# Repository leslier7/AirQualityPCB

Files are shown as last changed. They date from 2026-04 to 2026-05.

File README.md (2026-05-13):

# Air Quality PCB

A custom air quality monitoring device with an ESP32-C3 microcontroller, designed to measure environmental sensor data and transmit it over WiFi and LoRa.

## Repository Structure

```
AirQualityPCB/
├── PCB/        # KiCad schematic, layout, BOM, and fabrication outputs
└── Firmware/   # PlatformIO firmware for the ESP32-C3
```

## PCB

The PCB was designed in KiCad and lives in the [PCB/](PCB/) folder. This folder contains the schematic, board layout, and a custom component library (3D models, footprints, and symbols).

The BOM, STEP file, and Gerbers can be found on the [GitHub Releases](https://github.com/leslier7/AirQualityPCB/releases) page. They can also be extracted from the KiCAD project.

## Firmware

The firmware is written in C++ using the PlatformIO build system and targets the ESP32-C3.

For instructions on setting up the development environment, building, and flashing the firmware, see [Firmware/README.md](Firmware/README.md).

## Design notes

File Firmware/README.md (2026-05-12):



# About
Firmware for the Air Quality Monitoring board. Runs on an ESP32-C3 and reads the following sensors every 1.5–3 seconds, averaging the results before transmission:

| Sensor | Measurements |
|---|---|
| Bosch BME688 | Temperature, Humidity, Pressure, VOC gas resistance |
| CH4 sensor (UART) | Methane (ppm) |
| H2S sensor (I2C via ADS1X15 ADC) | Hydrogen sulfide (ppm) |
| NO2 sensor (I2C via ADS1X15 ADC) | Nitrogen dioxide (ppm) |

Data is transmitted over LoRaWAN to [The Things Network](https://www.thethingsnetwork.org/) every 15 minutes. Uplinks are unconfirmed by default; a confirmed uplink (which solicits an ACK downlink from TTN) is sent at most every 10th transmission to stay within TTN's fair use policy of 10 downlink messages per 24 hours.

### Packet Format
All fields are little-endian integers transmitted over LoRaWAN port 1.

| Field | Type | Scale | Range | Unit |
|---|---|---|---|---|
| `ch4` | `uint16` | ×1 | 0–65535 | ppm |
| `h2s` | `uint16` | ×100 | 0–5000 → 0.00–50.00 | ppm |
| `nox` | `uint16` | ×100 | 0–30000 → 0.00–300.00 | ppm |
| `voc_load` | `uint16` | ×1 | 0–65535 | (1/Ω)×10⁶×10 |
| `temp` | `int16` | ×100 | -4000–8500 → -40.00–85.00 | °C |
| `humidity` | `uint16` | ×100 | 0–10000 → 0.00–100.00 | %RH |
| `pressure` | `uint16` | ×10 | — | hPa |

---

# Contributing Guidelines

### Development Environment Setup
1. Install a C/C++ IDE which supports PlatformIO (e.g. [Visual Studio Code](https://code.visualstudio.com/), [CLion](https://www.jetbrains.com/clion/)).
2. Install [PlatformIO](https://platformio.org/install/) as an extension in your IDE.
3. Open the `Firmware` folder in your IDE.
4. Open the PlatformIO Home from the PlatformIO extension in your IDE.
5. Make sure to select the environment which corresponds to the board you are using (see **Build Environments** below).
6. Build the project using the PlatformIO build button.
7. Upload the project to the ESP32-C3 board using the PlatformIO upload button.
8. Open the serial monitor to view the output. (If using CLion, use the CLion Serial Monitor Plugin rather than the built-in upload-and-monitor button.)
9. Make changes to the code and test them on the board.
10. If you are adding new libraries, add them to `platformio.ini`.
11. Develop your changes in a separate Git branch.

### Build Environments

| Environment | Description |
|---|---|
| `lora` | Standard LoRaWAN build — use this for production |
| `test` | LoRaWAN build with zeroed sensor values (safe for RF testing without real sensors) |
| `long-range` | LoRaWAN build using SF10 for extended range |
| `long-range-debug` | SF10 build with confirmed uplinks on every TX (exceeds TTN fair use — bench only) |
| `wifi` | WiFi build (development/alternative transport) |

Select the environment from the PlatformIO toolbar before building and uploading.

### Code Style
TODO

### Pull Request Guidelines
Please write a brief description of what your code changed and why. Set yourself as the assignee and assign Robbie (leslier7) as the reviewer. Do not merge until Robbie has reviewed and approved.

# Configuration

### LoRa Configuration
To connect the board to The Things Network via LoRaWAN, you need a `keys.h` file containing your device credentials. **This file must never be committed to version control.**

1. Register your device in the [TTN Console](https://console.cloud.thethings.network/) using OTAA activation.
2. Create a new file named `keys.h` in the `include` directory.
3. Copy and paste the following template into `keys.h`:

```c
#include "stdint.h"
#ifndef KEYS_H
#define KEYS_H

// App EUI — 8 bytes, LSB first (from TTN console, "JoinEUI")
const uint8_t PROGMEM APPEUI[8] = { 0x00, 0x00, 0x00, 0x00, 0x00, 0x00, 0x00, 0x00 };

// Dev EUI — 8 bytes, LSB first (from TTN console, copy as "lsb" byte order)
const uint8_t PROGMEM DEVEUI[8] = { 0x00, 0x00, 0x00, 0x00, 0x00, 0x00, 0x00, 0x00 };

// App Key — 16 bytes, MSB first (from TTN console, copy as "msb" byte order)
const uint8_t PROGMEM APPKEY[16] = { 0x00, 0x00, 0x00, 0x00, 0x00, 0x00, 0x00, 0x00,
                                     0x00, 0x00, 0x00, 0x00, 0x00, 0x00, 0x00, 0x00 };

#endif
```

4. Replace each byte array with your actual device credentials from the TTN console.
   - **APPEUI / JoinEUI**: copy in **LSB** (least-significant byte first) order.
   - **DEVEUI**: copy in **LSB** order.
   - **APPKEY**: copy in **MSB** (most-significant byte first) order.

The firmware is configured for the **US915** region. To change region, edit the `CFG_*` build flag in `platformio.ini`.

TTN fair use limits confirmed uplinks to at most 10 per 24 hours. The firmware enforces this automatically — do not use the `long-range-debug` environment in the field.

### WiFi Configuration
In order to connect the board to WiFi, please follow the steps below:

1. Create a new file named `wifi_secrets.h` in the `include` directory.
2. Copy and paste the following code into the `wifi_secrets.h` file:

```c
#ifndef WIFI_SECRETS_H
#define WIFI_SECRETS_H

#define WIFI_SSID "your_ssid"
#define WIFI_PASSWORD "your_password"
#define CLIENT_NAME "your_client_name"
#define CLIENT_KEY "your_client_key"

#endif //WIFI_SECRETS_H
```

3. Replace `your_ssid` with your actual Wi-Fi network name (SSID).
4. Replace `your_password` with your actual Wi-Fi password (with the quotation marks still).
5. Replace `your_client_name` with your client name from the backend.
6. Replace `your_client_key` with your client key that was generated by the backend during onboarding.

Please ensure that you do not share your `wifi_secrets.h` file publicly or commit it to version control, as it contains sensitive information.

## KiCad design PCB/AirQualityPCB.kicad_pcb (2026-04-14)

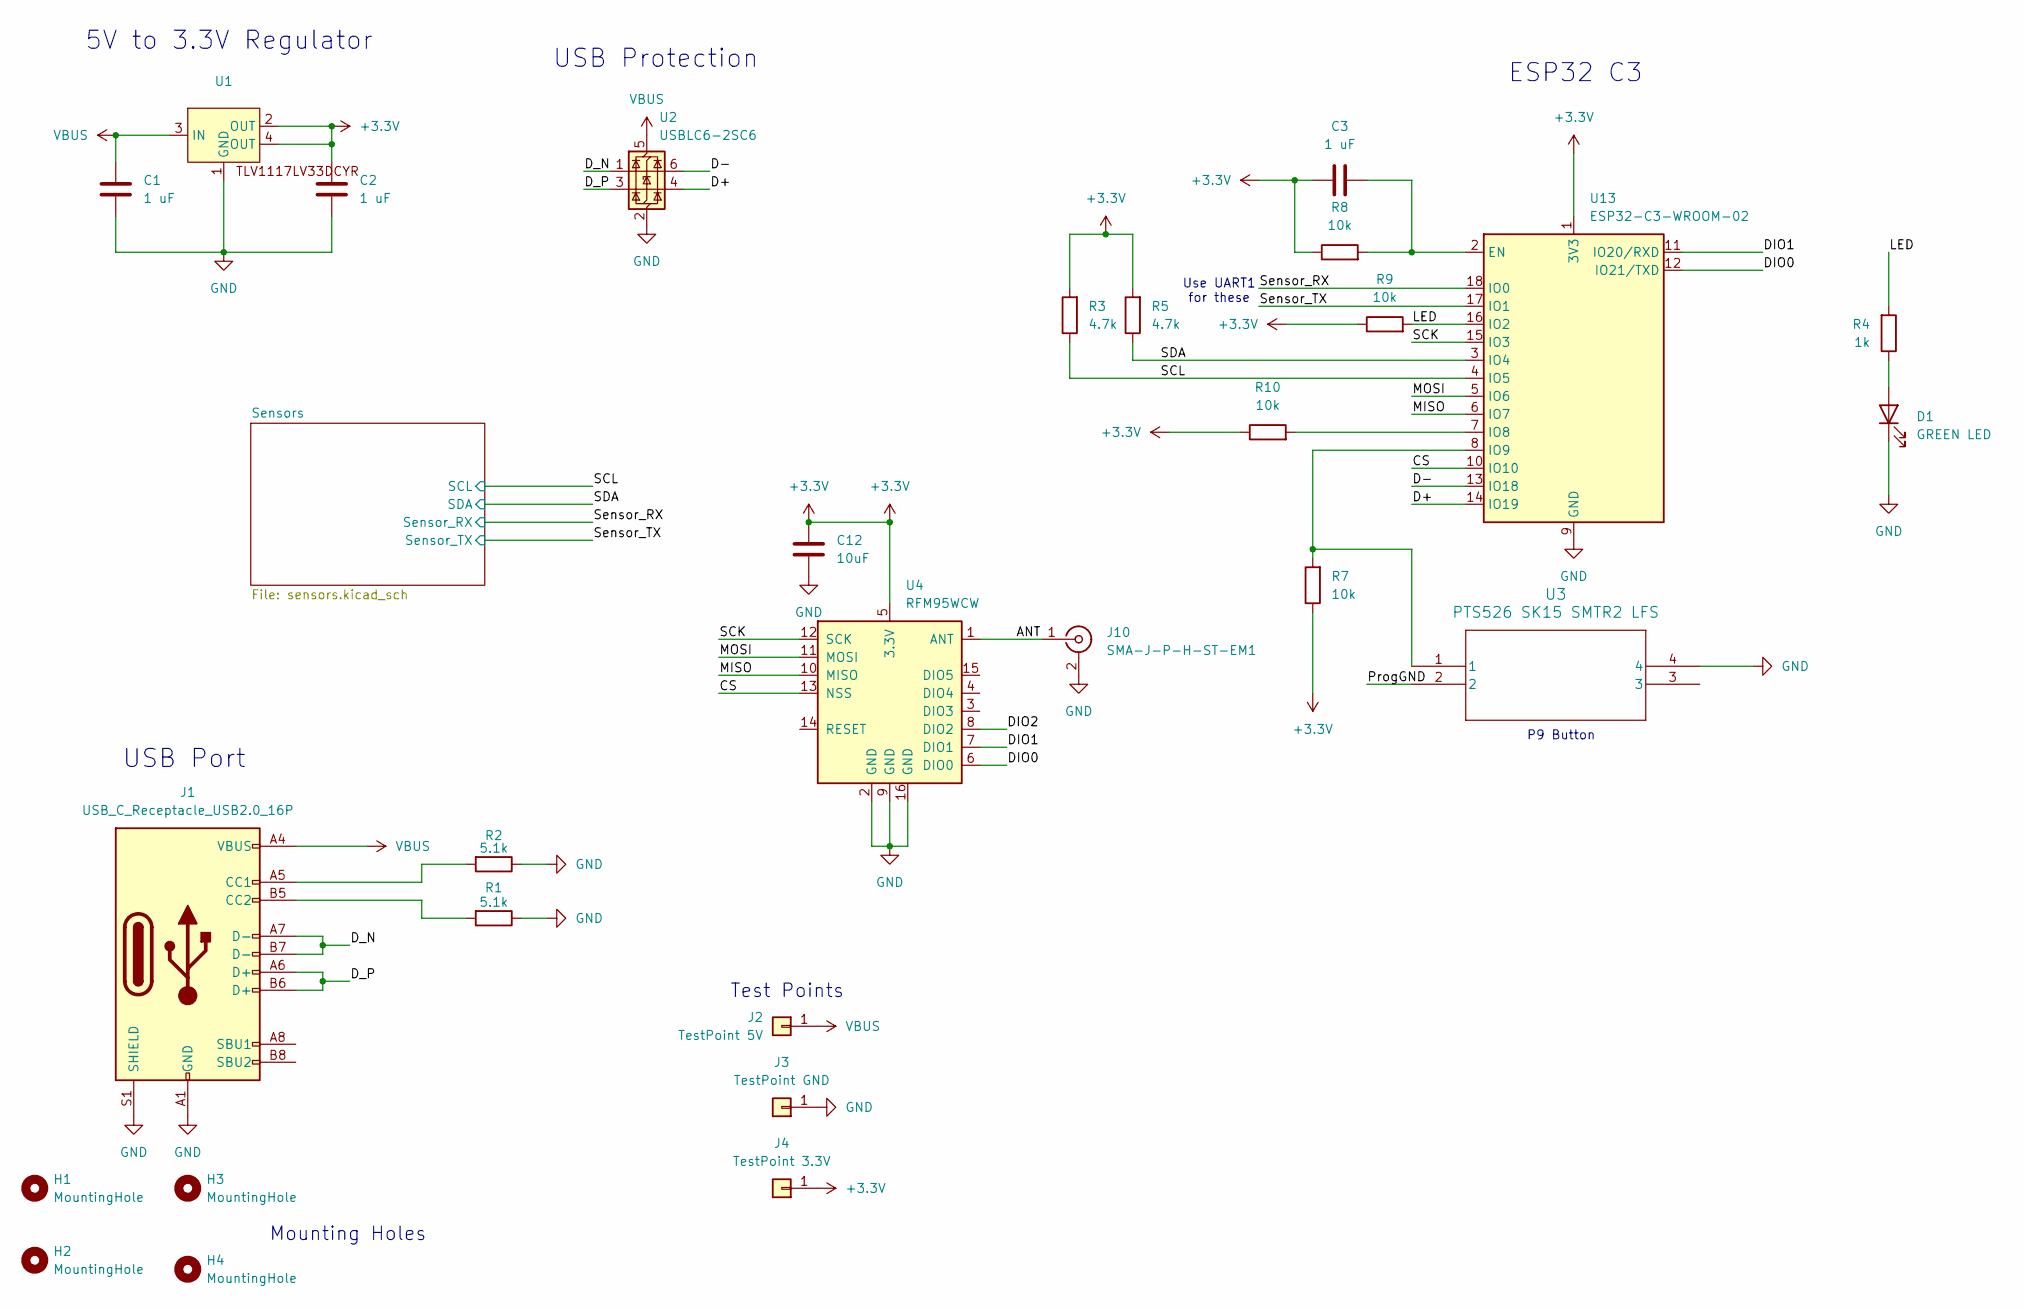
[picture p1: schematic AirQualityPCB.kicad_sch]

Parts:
C1, C2, C3: 1 uF; C_1206_3216Metric; Manufacturer Part Number CL31B105KCHNNNE
C12: 10uF; C_1206_3216Metric; Manufacturer Part Number TMK316BJ106KL-T
D1: GREEN LED; LED_1206_3216Metric; Manufacturer Part Number HSMG-C150
H1, H2, H3, H4: MountingHole; MountingHole_3.2mm_M3_ISO7380_Pad
J1: USB_C_Receptacle_USB2.0_16P; USB_C_Receptacle_GCT_USB4105-xx-A_16P_TopMnt_Horizontal; Manufacturer Part Number USB4105-GF-A
J2: TestPoint 5V; TestPoint_Pad_D1.0mm
J3: TestPoint GND; TestPoint_Pad_D1.0mm
J4: TestPoint 3.3V; TestPoint_Pad_D1.0mm
J10: SMA-J-P-H-ST-EM1; SMA_Samtec_SMA-J-P-H-ST-EM1_EdgeMount; Manufacturer Part Number SMA-J-P-H-ST-EM1
R1, R2: 5.1k; R_1206_3216Metric; Manufacturer Part Number CRCW12065K10FKEA
R3, R5: 4.7k; R_1206_3216Metric; Manufacturer Part Number RT1206FRE074K7L
R4: 1k; R_1206_3216Metric; Manufacturer Part Number RC1206FR-071KL
R7, R8, R9, R10: 10k; R_0805_2012Metric; Manufacturer Part Number RR1220P-103-D
U1: Regulator; SOT-223; Manufacturer Part Number TLV1117LV33DCYR
U2: USBLC6-2SC6; SOT-23-6; Manufacturer Part Number USBLC6-2SC6
U3: PTS526 SK15 SMTR2 LFS; PTS526SK15SMTR2 LFS; Manufacturer Part Number PTS526SK15SMTR2 LFS
U4: RFM95WCW; HOPERF_RFM9XW_SMD; Manufacturer Part Number COM-18085
U13: ESP32-C3-WROOM-02; Manufacturer Part Number ESP32-C3-WROOM-02-N4

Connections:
+3.3V: C2.2, C3.1, C12.2, J4.1, R3.2, R5.2, R7.1, R8.1, R9.1, R10.1, U1.2 (OUT), U1.4 (OUT), U4.5 (3.3V), U13.1 (3V3); also elsewhere on the board
/ANT: J10.1 (In), U4.1 (ANT)
/CS: U4.13 (NSS), U13.10 (IO10)
/D+: U2.4 (I/O2), U13.14 (IO19)
/D-: U2.6 (I/O1), U13.13 (IO18)
/DIO0: U4.6 (DIO0), U13.12 (IO21/TXD)
/DIO1: U4.7 (DIO1), U13.11 (IO20/RXD)
/DIO2: U4.8 (DIO2)
/D_N: J1.A7 (D-), J1.B7 (D-), U2.1 (I/O1)
/D_P: J1.A6 (D+), J1.B6 (D+), U2.3 (I/O2)
/LED: R4.2, R9.2, U13.16 (IO2)
/MISO: U4.10 (MISO), U13.6 (IO7)
/MOSI: U4.11 (MOSI), U13.5 (IO6)
/ProgGND: U3.2
/SCK: U4.12 (SCK), U13.15 (IO3)
/SCL: R3.1, U13.4 (IO5); also elsewhere on the board
/SDA: R5.1, U13.3 (IO4); also elsewhere on the board
/Sensor_RX: U13.18 (IO0); also elsewhere on the board
/Sensor_TX: U13.17 (IO1); also elsewhere on the board
GND: C1.1, C2.1, C12.1, D1.1 (K), J1.A1 (GND), J1.A12 (GND), J1.B1 (GND), J1.B12 (GND), J1.S1 (SHIELD), J3.1, J10.2 (Ext), R1.1, R2.1, U1.1 (GND), U2.2 (GND), U3.4, U4.2 (GND), U4.9 (GND), U4.16 (GND), U13.9 (GND), U13.19 (GND); also elsewhere on the board
unnamed: D1.2 (A), R4.1
unnamed: J1.A5 (CC1), R2.2
unnamed: J1.B5 (CC2), R1.2
unnamed: C3.2, R8.2, U13.2 (EN)
unnamed: R10.2, U13.7 (IO8)
unnamed: R7.2, U3.1, U13.8 (IO9)
VBUS: C1.2, J1.A4 (VBUS), J1.A9 (VBUS), J1.B4 (VBUS), J1.B9 (VBUS), J2.1, U1.3 (IN), U2.5 (VBUS)

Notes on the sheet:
USB Protection
5V to 3.3V Regulator
Test Points
Use UART1 for these
Mounting Holes
P9 Button
ESP32 C3
USB Port

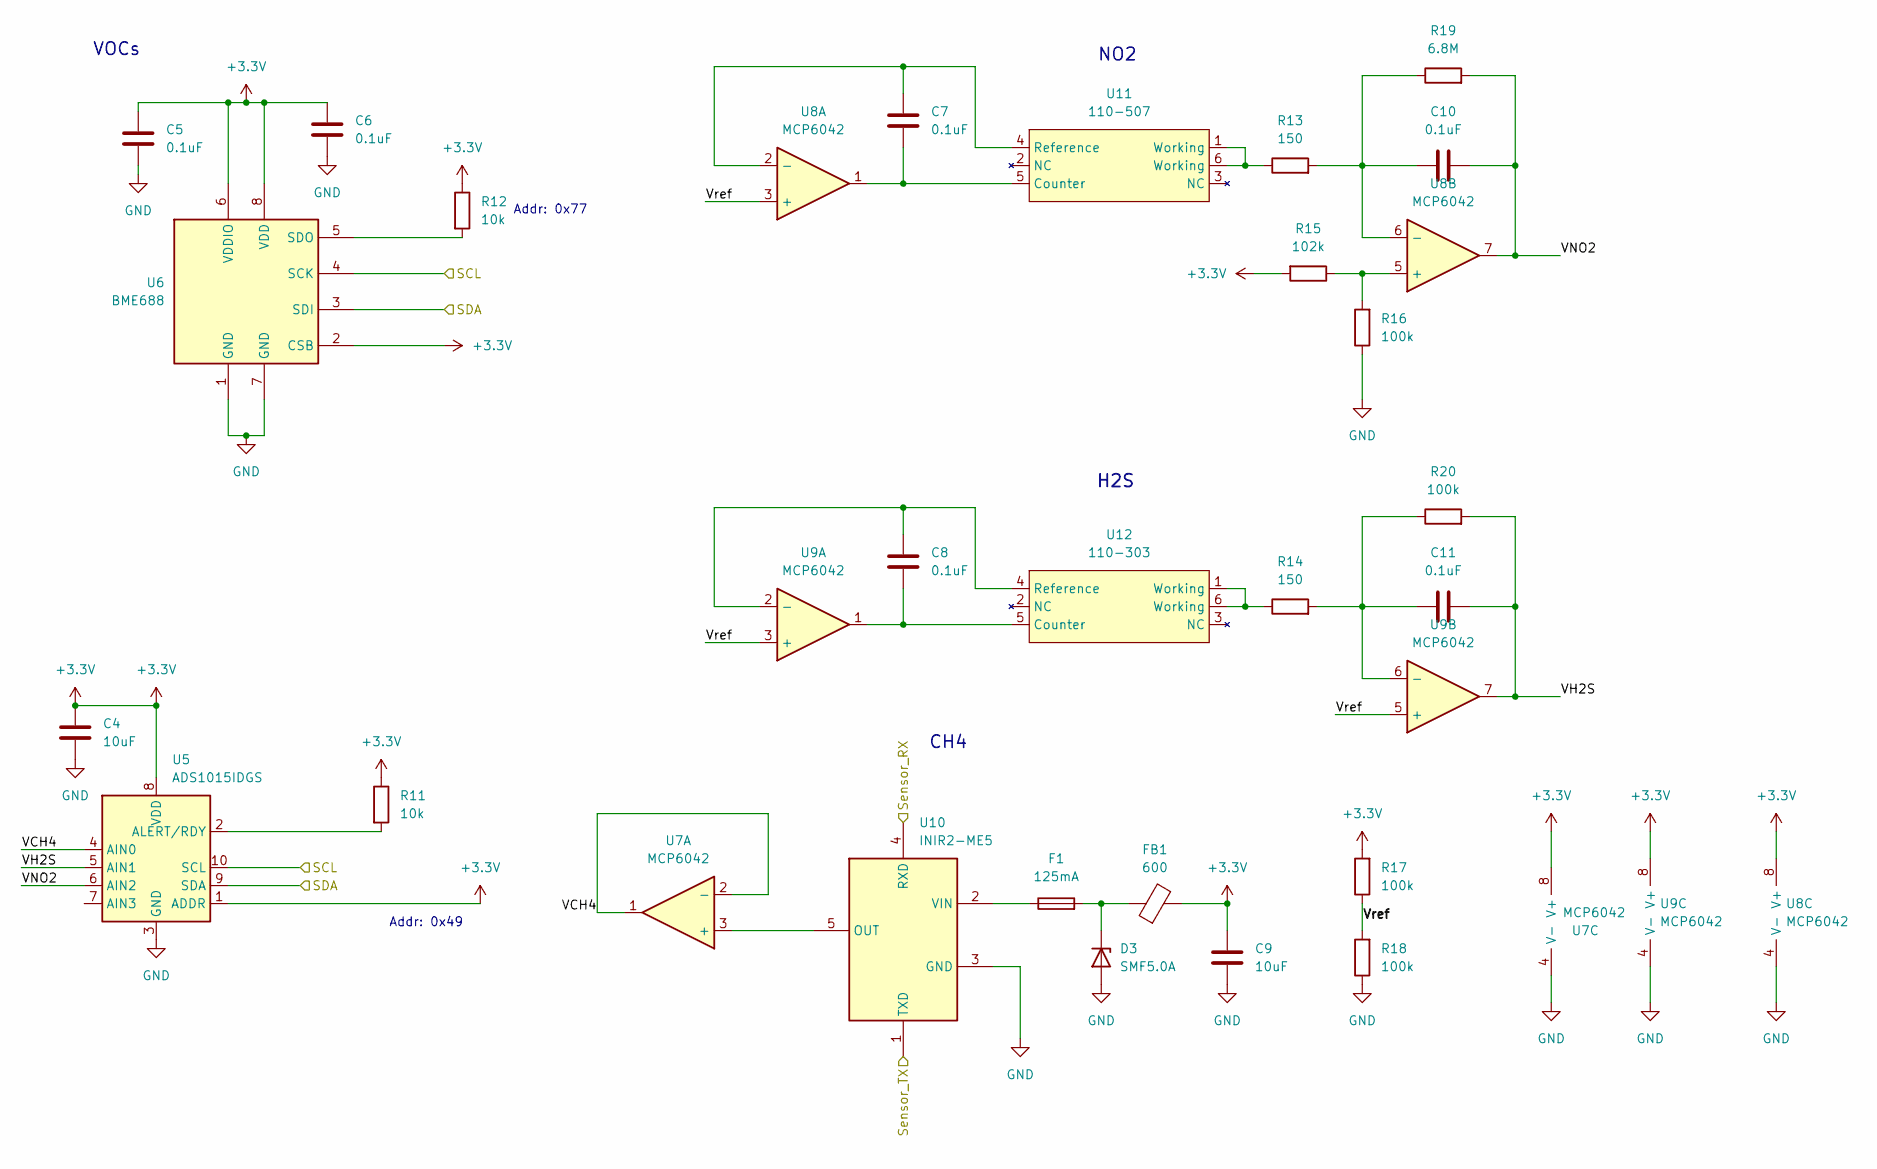
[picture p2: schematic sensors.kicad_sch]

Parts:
C4, C9: 10uF; C_1206_3216Metric; Manufacturer Part Number TMK316BJ106KL-T
C5, C6, C7, C8, C10, C11: 0.1uF; C_0805_2012Metric; Manufacturer Part Number C0805F104K1RACAUTO
D3: SMF5.0A; D_SOD-123; Manufacturer Part Number SMF5.0A
F1: 125mA; Fuse_1206_3216Metric; Manufacturer Part Number 0466.125NRHF
FB1: 600; L_1206_3216Metric; Manufacturer Part Number 742792133
R11, R12: 10k; R_0805_2012Metric; Manufacturer Part Number RR1220P-103-D
R13, R14: 150; R_0603_1608Metric; Manufacturer Part Number ERA-3AEB151V
R15: 102k; R_0603_1608Metric; Manufacturer Part Number RC0603FR-07102KL
R16, R17, R18, R20: 100k; R_0603_1608Metric; Manufacturer Part Number RC0603FR-07100KL
R19: 6.8M; R_0603_1608Metric; Manufacturer Part Number RC0603JR-076M8L
U5: ADS1015IDGS; TSSOP-10_3x3mm_P0.5mm; Manufacturer Part Number ADS1015IDGSR
U6: BME688; Bosch_LGA-8_3x3mm_P0.8mm_ClockwisePinNumbering; Manufacturer Part Number BME688
U7, U8, U9: MCP6042; SOIC-8_3.9x4.9mm_P1.27mm; Manufacturer Part Number MCP6042T-I/SN
U10: INIR2-ME5; INIR2ME5; Manufacturer Part Number INIR2-ME5
U11: 110-507; 110-Footprint; Manufacturer Part Number 110-507
U12: 110-303; 110-Footprint; Manufacturer Part Number 110-303

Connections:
+3.3V: C4.1, C5.1, C6.1, C9.1, FB1.2, R11.1, R12.1, R15.2, R17.2, U5.1 (ADDR), U5.8 (VDD), U6.2 (CSB), U6.6 (VDDIO), U6.8 (VDD), U7.8 (V+), U8.8 (V+), U9.8 (V+); also elsewhere on the board
/SCL: U5.10 (SCL), U6.4 (SCK); also elsewhere on the board
/SDA: U5.9 (SDA), U6.3 (SDI); also elsewhere on the board
/Sensor_RX: U10.4 (RXD); also elsewhere on the board
/Sensor_TX: U10.1 (TXD); also elsewhere on the board
/Sensors/VCH4: U5.4 (AIN0), U7.1, U7.2 (-)
/Sensors/VH2S: C11.2, R20.2, U5.5 (AIN1), U9.7
/Sensors/VNO2: C10.2, R19.2, U5.6 (AIN2), U8.7
/Sensors/Vref: R17.1, R18.2, U8.3 (+), U9.3 (+), U9.5 (+)
GND: C4.2, C5.2, C6.2, C9.2, D3.2 (A), R16.1, R18.1, U5.3 (GND), U6.1 (GND), U6.7 (GND), U7.4 (V-), U8.4 (V-), U9.4 (V-), U10.3 (GND); also elsewhere on the board
unnamed: D3.1 (K), F1.2, FB1.1
unnamed: R13.1, U11.1 (Working), U11.6 (Working)
unnamed: R14.1, U12.1 (Working), U12.6 (Working)
unnamed: R11.2, U5.2 (ALERT/RDY)
unnamed: R12.2, U6.5 (SDO)
unnamed: R15.1, R16.2, U8.5 (+)
unnamed: C10.1, R13.2, R19.1, U8.6 (-)
unnamed: C11.1, R14.2, R20.1, U9.6 (-)
unnamed: U7.3 (+), U10.5 (OUT)
unnamed: F1.1, U10.2 (VIN)
unnamed: C7.2, U8.1, U11.5 (Counter)
unnamed: C7.1, U8.2 (-), U11.4 (Reference)
unnamed: C8.2, U9.1, U12.5 (Counter)
unnamed: C8.1, U9.2 (-), U12.4 (Reference)

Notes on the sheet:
NO2
H2S
Addr: 0x49
CH4
Addr: 0x77
VOCs

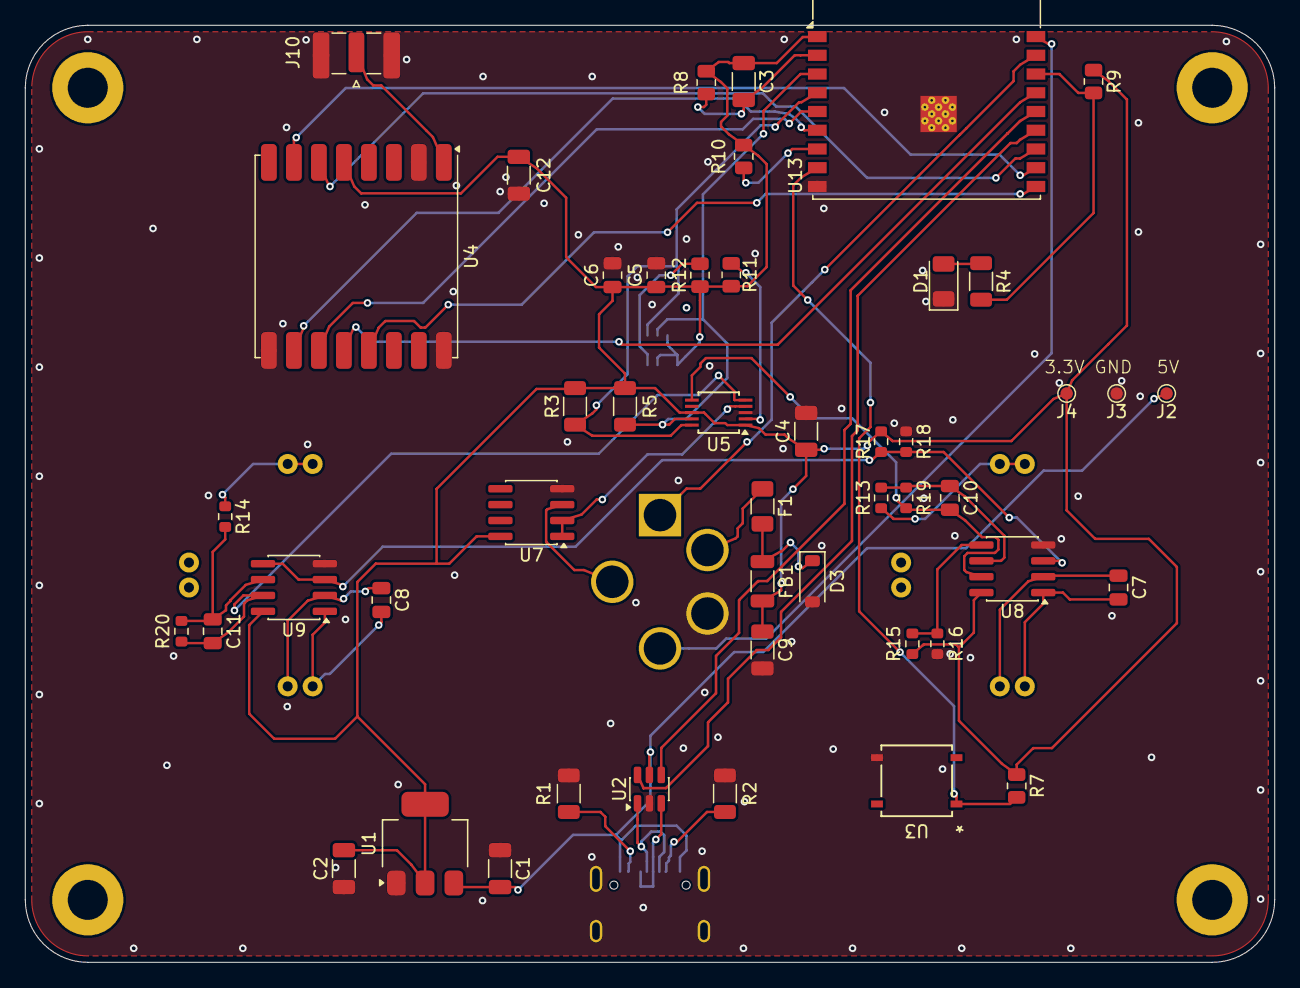
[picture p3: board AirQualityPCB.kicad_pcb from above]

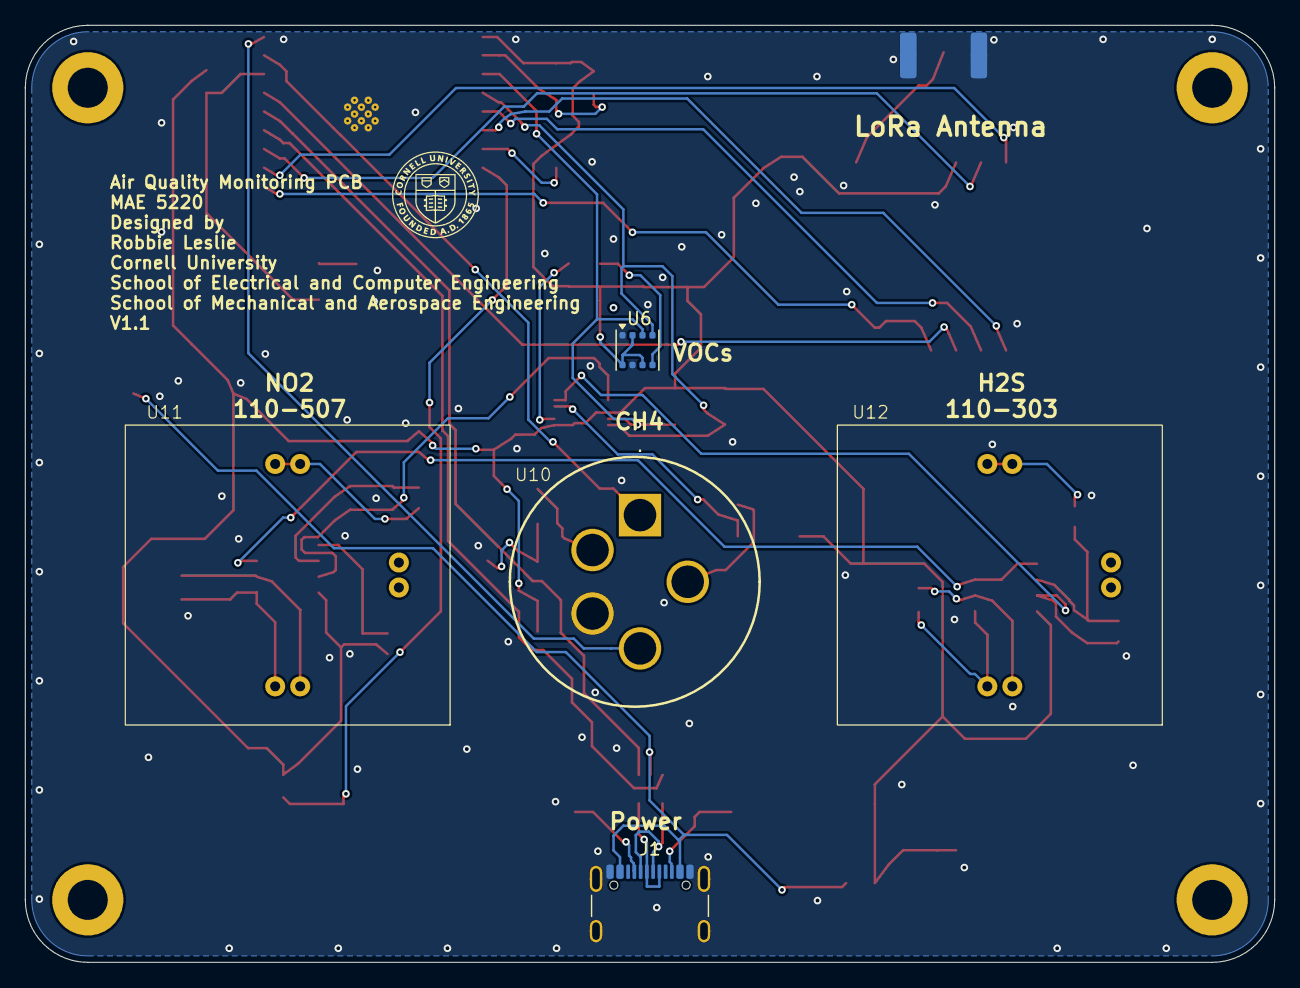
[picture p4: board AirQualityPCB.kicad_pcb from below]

Board: 2 copper layers, 100.0 x 75.0 mm, 57 parts (5 on the bottom side), 43 nets.

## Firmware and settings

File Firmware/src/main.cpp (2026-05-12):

// Air Quality Monitoring
// Robbie Leslie April 2026

#include <Arduino.h>
#include "sensors.h"
#include "scheduler.h"

#ifdef LORA
#include "lora.h"
#elif defined(WIFI)
#include "wifi.h"
#endif

#define LED 2

#ifdef LORA
pkt_fmt myPkt;
#endif

// --- Averaging accumulators -------------------------------------------------
 
struct {
    float    voc_load;
    float    temp;
    float    humidity;
    float    pressure;
    uint32_t n;
} bme_acc = {};
 
struct {
    float    ch4;
    uint32_t ch4_n;
    float    h2s;
    uint32_t h2s_n;
    float    nox;
    uint32_t nox_n;
} gas_acc = {};
 
static void reset_accumulators() {
    bme_acc = {};
    gas_acc = {};
}


// --- Scheduled tasks --------------------------------------------------------

void task_read_bme() {
    update_BME();
    BMEReading bme = get_BME_reading();
    if (bme.raw_gas > 0.0f) {
        myPkt.voc_load = (uint16_t)constrain((1.0f / bme.raw_gas) * 1e6f * 10.0f, 0, 65535);
    } else {
        myPkt.voc_load = 0;
    }
    myPkt.temp        = (int16_t)(bme.temperature * 100.0f);
    myPkt.humidity    = (uint16_t)(bme.humidity * 100.0f);
    myPkt.pressure    = (uint16_t)(bme.pressure * 10.0f);
    Serial.printf("Voc load: %d  Temp: %.2f  Humidity: %.2f Pressure: %.2f\n", myPkt.voc_load, bme.temperature, bme.humidity, bme.pressure);
}

void task_read_gases() {
    uint16_t ch4 = read_methane_uart();
    float h2s = read_h2s_ppm();
    float no2 = read_no2_ppm();

    if (ch4 != 65535) {
        gas_acc.ch4 += ch4;
        gas_acc.ch4_n++;
    }
    gas_acc.h2s += h2s;
    gas_acc.h2s_n++;
    gas_acc.nox += no2;
    gas_acc.nox_n++;
 
    Serial.printf("CH4: %d ppm H2S: %.2f ppm  NO2: %.2f ppm\n", ch4, h2s, no2);

}

void task_send_lora() {
    if (!g_joined) return;
    if (LMIC.devaddr != 0) {

        #ifdef TEST
        myPkt.ch4 = 0;
        myPkt.h2s = 0;
        myPkt.nox = 0;
        myPkt.humidity = 0;
        myPkt.temp = 0;
        myPkt.voc_load = 0;

        #else
        // Flush BME averages into packet
        if (bme_acc.n > 0) {
            myPkt.voc_load = (uint16_t)(bme_acc.voc_load / bme_acc.n);
            myPkt.temp     = (int16_t)((bme_acc.temp     / bme_acc.n) * 100.0f);
            myPkt.humidity = (uint16_t)((bme_acc.humidity / bme_acc.n) * 100.0f);
            myPkt.pressure = (uint16_t)((bme_acc.pressure / bme_acc.n) * 10.0f);
        }
        // Flush gas averages into packet
        if (gas_acc.ch4_n > 0)
            myPkt.ch4 = (uint16_t)(gas_acc.ch4 / gas_acc.ch4_n);
        if (gas_acc.h2s_n > 0)
            myPkt.h2s = (uint16_t)constrain((gas_acc.h2s / gas_acc.h2s_n) * 100.0f, 0, 5000);
        if (gas_acc.nox_n > 0)
            myPkt.nox = (uint16_t)constrain((gas_acc.nox / gas_acc.nox_n) * 100.0f, 0, 30000);
        
        #endif

        Serial.printf("TX averages — CH4: %d  H2S: %d  NOx: %d  Temp: %d  Hum: %d  VOC: %d\n",
            myPkt.ch4, myPkt.h2s, myPkt.nox, myPkt.temp, myPkt.humidity, myPkt.voc_load);
        
        uint8_t *raw = (uint8_t*)&myPkt;
        Serial.print("RAW PKT: ");
        for (int i = 0; i < (int)sizeof(myPkt); i++)
            Serial.printf("%02X ", raw[i]);
        Serial.println();
        
        send_lora(myPkt);
        reset_accumulators();
 
        digitalWrite(LED, HIGH);
        delay(50);
        digitalWrite(LED, LOW);
    }
}


Task tasks[] = {
    #ifndef TEST
    { task_read_bme,   1500,  0 },
    { task_read_gases, 3000,  0 },
    #endif
    { task_send_lora,  TX_INTERVAL_MS, 0 },
};

Scheduler scheduler(tasks, sizeof(tasks) / sizeof(tasks[0]));

// ----------------------------------------------------------------------------

// void setup() {
//     Serial.begin(115200);
//     Serial0.begin(38400, SERIAL_8N1, CH4_RX, CH4_TX);
//     delay(2000);
// }

// void loop() {
//     Serial0.print("[C]");
//     delay(10);  // 100 commands per second
// }

void setup() {
    pinMode(LED, OUTPUT);
    digitalWrite(LED, HIGH);
    delay(1000);
    digitalWrite(LED, LOW);
    Serial.begin(115200);
    delay(500);
    Serial.println("Air Quality Monitor starting");

    setup_I2C();
    setup_sensors();
    testPortI2C(Wire);

    myPkt.ch4 = 0;
    myPkt.h2s = 0;
    myPkt.nox = 0;
    myPkt.humidity = 0;
    myPkt.temp = 0;
    myPkt.voc_load = 0;

    #ifndef TEST
    if (!setup_lora())
        Serial.println("LoRaWAN init failed");
    #endif

    

    #ifndef TEST
    send_lora(myPkt);   // initial transmission before scheduler takes over
    #endif
    scheduler.begin();  // start all task clocks from now
}

void loop() {
    #ifndef TEST
    myLoRaWAN.loop();
    #endif
    scheduler.run();
}

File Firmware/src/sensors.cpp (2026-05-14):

// Robbie Leslie
// April 2026

#include "sensors.h"
#include <Arduino.h>
#include <Wire.h>
#include <Adafruit_ADS1X15.h>
#include <bme68xLibrary.h>
#include <HardwareSerial.h>

// SPEC sensor calibration (sensitivity in nA/ppm)
#define H2S_SENSITIVITY_NA_PER_PPM   212.0f   // typical for 110-303, replace per-unit
#define NO2_SENSITIVITY_NA_PER_PPM   -30.0f   // typical for 110-507, NEGATIVE — replace per-unit

// Transimpedance gain resistors (from schematic)
#define H2S_TIA_GAIN_OHMS   100000.0f   // R20
#define NO2_TIA_GAIN_OHMS   6800000.0f  // R19

#define NO2_ZERO_OFFSET_PPM  0.00f

#define DAC_VOLTS 3.3f

#define CH4_RANGE 100

// ADC reference and bias
#define VREF_VOLTS          1.635f       // measured

// ADS1015 in default ±2.048V FSR mode: 1 LSB = 1.0 mV (12-bit signed, 11-bit + sign)
#define ADC_LSB_VOLTS       0.001f

HardwareSerial CH4Serial(1);

Adafruit_ADS1015 adc;
Bme68x bme;

bool setup_ch4 = false;

// Latest BME688 readings — updated by update_BME(), read by get_BME_reading()
static float bme_temperature = 0.0f;
static float bme_humidity    = 0.0f;
static float bme_pressure    = 0.0f;
static float bme_raw_gas     = 0.0f;

static bool bme_ready = false;

// --------------------------------------------------------------------------
// Public sensor functions
// --------------------------------------------------------------------------

void testPortI2C(TwoWire &i2c) {
    Serial.printf("Scanning... time (ms): %d\n", millis());
    uint8_t detected = 0;
    for (uint8_t addr = 1; addr < 127; addr++) {
        i2c.beginTransmission(addr);
        uint8_t retval = i2c.endTransmission();
        if (retval == 0) {
            Serial.printf("\t0x%02X detected\n", addr);
            detected++;
        }
    }
    if (!detected) {
        Serial.printf("\tNo device detected!\n");
    }
    Serial.println();
}

bool setup_I2C(){
    return Wire.begin(SDA_PIN, SCL_PIN);
}

bool setup_BME() {
    bme.begin(0x77, Wire);
    if (bme.checkStatus() != BME68X_OK) {
        Serial.printf("BME688: init failed (status %d)\n", bme.checkStatus());
        return false;
    }

    // Oversampling: temp x2, pressure x16, humidity x1
    bme.setTPH(BME68X_OS_2X, BME68X_OS_16X, BME68X_OS_1X);
    // Heater: 320°C for 150ms — reasonable general-purpose VOC setpoint
    bme.setHeaterProf(320, 150);

    bme_ready = true;
    Serial.println("BME688: ready");
    return true;
}

// Non-blocking forced-mode update. Call every loop() iteration.
// Triggers a measurement, then returns immediately. On subsequent calls,
// reads data once the measurement duration has elapsed (~175ms for this heater profile).
static uint32_t bme_ready_at_us = 0;
static bool     bme_measuring   = false;

void update_BME() {
    if (!bme_ready) return;

    uint32_t now = micros();

    if (!bme_measuring) {
        bme.setOpMode(BME68X_FORCED_MODE);
        bme_ready_at_us = now + bme.getMeasDur();
        bme_measuring = true;
        return;
    }

    if ((int32_t)(now - bme_ready_at_us) < 0) return;

    bme_measuring = false;
    bme68xData data;
    if (bme.fetchData()) {
        bme.getData(data);
        bme_temperature = data.temperature;
        bme_humidity    = data.humidity;
        bme_pressure    = data.pressure / 100.0f;
        bme_raw_gas     = (data.status & BME68X_GASM_VALID_MSK) ? data.gas_resistance : 0.0f;
    }
}

// Snapshot of the latest BME688 readings — call this when building your
// transmission payload.
BMEReading get_BME_reading() {
    return {
        .temperature = bme_temperature,
        .humidity    = bme_humidity,
        .pressure    = bme_pressure,
        .raw_gas     = bme_raw_gas,
    };
}

// Send a command and wait for [AK] or [NA]. Returns true on ACK.
static bool inir_cmd(const char* cmd, uint32_t timeoutMs = 500) {
    while (CH4Serial.available()) CH4Serial.read();  // flush
    
    Serial.printf("INIR2: TX bytes for '%s': ", cmd);
    for (size_t i = 0; cmd[i]; i++) {
        Serial.printf("0x%02X ", (uint8_t)cmd[i]);
    }
    Serial.println();
    
    CH4Serial.print(cmd);

    String response = "";
    uint32_t start = millis();
    Serial.print("INIR2: RX bytes: ");
    while (millis() - start < timeoutMs) {
        if (CH4Serial.available()) {
            char c = (char)CH4Serial.read();
            Serial.printf("0x%02X ", (uint8_t)c);
            response += c;
            if (c == ']') break;
        }
    }
    Serial.printf("\nINIR2: RX as string: '%s'\n", response.c_str());
    return response.indexOf("414b") >= 0;
}

bool setup_methane(){
    CH4Serial.end();
    delay(50);
    CH4Serial.begin(38400, SERIAL_8N1, CH4_TX, CH4_RX);

    // Datasheet Table 1: 38400 baud, 8 data bits, no parity, 1 stop bits
    //CH4Serial.begin(38400, SERIAL_8N1, CH4_RX, CH4_TX);
    delay(2000);

    // Listen for any spontaneous output
    // Serial.println("INIR2: listening for 3 seconds...");
    // uint32_t listen_start = millis();
    // while (millis() - listen_start < 3000) {
    //     if (CH4Serial.available()) {
    //         char c = (char)CH4Serial.read();
    //         Serial.printf("0x%02X ", (uint8_t)c);
    //     }
    // }
    // Serial.println("\nINIR2: done listening");

    // Initialization procedure (datasheet section 1.1.5):
    // Step 1: enter Configuration Mode
    Serial.println("INIR2: [C] config mode...");
    if (!inir_cmd("[C]")) {
        Serial.println("INIR2: no ACK to [C]");
        return false;
    }

    // Step 2: read back settings for operation check, then flush response
    CH4Serial.print("[I]");
    delay(300);
    while (CH4Serial.available()) CH4Serial.read();

    // Step 3: enter Engineering Mode — sensor starts streaming every 1s
    Serial.println("INIR2: [B] engineering mode...");
    if (!inir_cmd("[B]")) {
        Serial.println("INIR2: no ACK to [B]");
        return false;
    }
    Serial.println("INIR2: streaming started (45s warmup)");
    return true;
}

bool setup_sensors(){
    #ifndef TEST
    bool methane_setup = setup_methane();
    Serial.printf("Methane setup: %d\n", methane_setup);
    setup_BME();
    #endif

    bool adc_setup = adc.begin(0x49);
    adc.setGain(GAIN_TWO);  // ±2.048V FSR, 1mV/LSB — matches ADC_LSB_VOLTS

    return adc_setup;
}

// Returns %vol
float read_methane_adc(){
    int raw = adc.readADC_SingleEnded(0);
    float ch4 = ((raw/1.25)-1)*CH4_RANGE;
    return ch4;
}
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

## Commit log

2026-03-21 Started working on PCB
    [AirQualityPCB.kicad_pcb, AirQualityPCB.kicad_sch, sensors.kicad_sch]
2026-03-22 Finished schematic
    [AirQualityPCB.kicad_sch, sensors.kicad_sch]
2026-03-23 Finished first footprint (no routing)
    [AirQualityPCB.kicad_pcb, AirQualityPCB.kicad_sch, sensors.kicad_sch]
2026-03-23 Updated silkscreen
    [AirQualityPCB.kicad_pcb]
2026-03-25 Before routing
    [AirQualityPCB.kicad_pcb]
2026-03-25 Removed components pre quilter routing
    [AirQualityPCB.kicad_pcb, AirQualityPCB.kicad_sch, sensors.kicad_sch]
2026-03-26 v1.0 done
    [AirQualityPCB.kicad_pcb, AirQualityPCB.kicad_sch]
2026-04-06 Moved PCB into subfolder and started work on firmware
    [AirQualityPCB.kicad_pcb, AirQualityPCB.kicad_sch, sensors.kicad_sch]
2026-04-13 Fixed op amp short bug
    [AirQualityPCB.kicad_pcb, sensors.kicad_sch]
2026-04-13 Swapped LED to pin 2
    [AirQualityPCB.kicad_pcb, AirQualityPCB.kicad_sch]
2026-04-13 Swapped USB CC resistors
    [AirQualityPCB.kicad_pcb, AirQualityPCB.kicad_sch]
2026-04-14 Switched sockets, fixed USB, and SPI test
    [AirQualityPCB.kicad_pcb]
2026-04-14 Started work on collecting data from sensors
    [sensors.kicad_sch]
2026-04-14 Updated fuse and started work on talking with CH4 sensor
    [AirQualityPCB.kicad_pcb, sensors.kicad_sch]
2026-04-27 Continued work on reading sensors
2026-05-12 Fixed too frequent downlinks
    [lora.cpp, lora.h, main.cpp]
2026-05-14 Fixed H2S offset bug
    [sensors.cpp]
